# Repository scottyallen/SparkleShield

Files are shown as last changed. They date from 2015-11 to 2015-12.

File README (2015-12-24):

The Sparkle Shield is an add-on shield for Arduino that has 70 individually
programmable full color LEDs arranged in a 7x10 matrix. It comes as an
unassembled kit that you can solder yourself with a few basic tools.  The
Sparkle Shield comes with a bunch of cool animations, but it's also easy to
program your own using the free Arduino development kit (compatible with
PC/Mac/Linux) and the Sparkle Shield Arduino library.

For more information and assembly and programming instructions, go to
http://sparkleshield.com.

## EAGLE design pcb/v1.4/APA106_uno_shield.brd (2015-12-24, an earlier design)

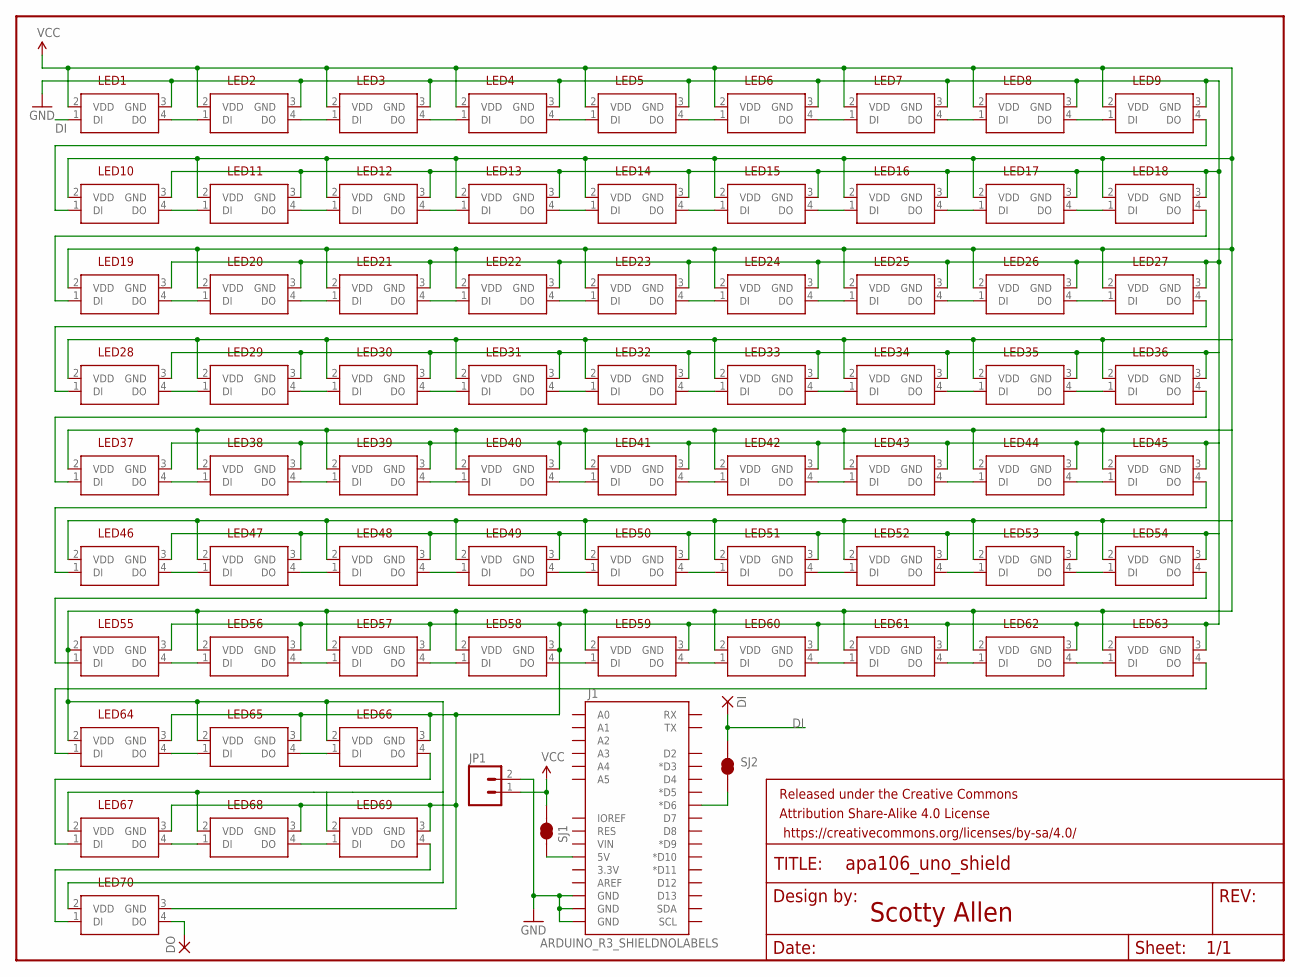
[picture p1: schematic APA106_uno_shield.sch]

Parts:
DI: 1,6/0,9
DO: 1,6/0,9
FRAME1: FRAME-LETTER; CREATIVE_COMMONS
J1: ARDUINO_R3_SHIELDNOLABELS; UNO_R3_SHIELD_NOLABELS
JP1: M02PTH; 1X02
LED1, LED2, LED3, LED4, LED5, LED6, LED7, LED8, LED9, LED10, LED11, LED12, LED13, LED14, LED15, LED16, LED17, LED18, LED19, LED20, LED21, LED22, LED23, LED24, LED25, LED26, LED27, LED28, LED29, LED30, LED31, LED32, LED33, LED34, LED35, LED36, LED37, LED38, LED39, LED40, LED41, LED42, LED43, LED44, LED45, LED46, LED47, LED48, LED49, LED50, LED51, LED52, LED53, LED54, LED55, LED56, LED57, LED58, LED59, LED60, LED61, LED62, LED63, LED64, LED65, LED66, LED67, LED68, LED69, LED70: LED-APA106HOLE-OFFSET-SPREAD; LED-5MM-4PIN-HOLE-OFFSET-SPREAD
SJ1, SJ2: JUMPER-PAD-2-NC_BY_TRACENO_SILK; PAD-JUMPER-2-NC_BY_TRACE_NO_SILK

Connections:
DI: DI.1, LED1.1 (DI), SJ2.2
GND: J1.GND@0 (GND), J1.GND@1 (GND), J1.GND@2 (GND), JP1.2, LED1.3 (GND), LED2.3 (GND), LED3.3 (GND), LED4.3 (GND), LED5.3 (GND), LED6.3 (GND), LED7.3 (GND), LED8.3 (GND), LED9.3 (GND), LED10.3 (GND), LED11.3 (GND), LED12.3 (GND), LED13.3 (GND), LED14.3 (GND), LED15.3 (GND), LED16.3 (GND), LED17.3 (GND), LED18.3 (GND), LED19.3 (GND), LED20.3 (GND), LED21.3 (GND), LED22.3 (GND), LED23.3 (GND), LED24.3 (GND), LED25.3 (GND), LED26.3 (GND), LED27.3 (GND), LED28.3 (GND), LED29.3 (GND), LED30.3 (GND), LED31.3 (GND), LED32.3 (GND), LED33.3 (GND), LED34.3 (GND), LED35.3 (GND), LED36.3 (GND), LED37.3 (GND), LED38.3 (GND), LED39.3 (GND), LED40.3 (GND), LED41.3 (GND), LED42.3 (GND), LED43.3 (GND), LED44.3 (GND), LED45.3 (GND), LED46.3 (GND), LED47.3 (GND), LED48.3 (GND), LED49.3 (GND), LED50.3 (GND), LED51.3 (GND), LED52.3 (GND), LED53.3 (GND), LED54.3 (GND), LED55.3 (GND), LED56.3 (GND), LED57.3 (GND), LED58.3 (GND), LED59.3 (GND), LED60.3 (GND), LED61.3 (GND), LED62.3 (GND), LED63.3 (GND), LED64.3 (GND), LED65.3 (GND), LED66.3 (GND), LED67.3 (GND), LED68.3 (GND), LED69.3 (GND), LED70.3 (GND)
unnamed: LED1.4 (DO), LED2.1 (DI)
unnamed: LED2.4 (DO), LED3.1 (DI)
unnamed: LED3.4 (DO), LED4.1 (DI)
unnamed: LED4.4 (DO), LED5.1 (DI)
unnamed: LED6.4 (DO), LED7.1 (DI)
unnamed: LED7.4 (DO), LED8.1 (DI)
unnamed: LED37.4 (DO), LED38.1 (DI)
unnamed: LED5.4 (DO), LED6.1 (DI)
unnamed: LED8.4 (DO), LED9.1 (DI)
unnamed: LED10.4 (DO), LED11.1 (DI)
unnamed: LED19.4 (DO), LED20.1 (DI)
unnamed: LED20.4 (DO), LED21.1 (DI)
unnamed: LED11.4 (DO), LED12.1 (DI)
unnamed: LED12.4 (DO), LED13.1 (DI)
unnamed: LED21.4 (DO), LED22.1 (DI)
unnamed: LED22.4 (DO), LED23.1 (DI)
unnamed: LED18.4 (DO), LED19.1 (DI)
unnamed: LED23.4 (DO), LED24.1 (DI)
unnamed: LED13.4 (DO), LED14.1 (DI)
unnamed: LED9.4 (DO), LED10.1 (DI)
unnamed: LED14.4 (DO), LED15.1 (DI)
unnamed: LED15.4 (DO), LED16.1 (DI)
unnamed: LED16.4 (DO), LED17.1 (DI)
unnamed: LED17.4 (DO), LED18.1 (DI)
unnamed: LED24.4 (DO), LED25.1 (DI)
unnamed: LED25.4 (DO), LED26.1 (DI)
unnamed: LED26.4 (DO), LED27.1 (DI)
unnamed: LED28.4 (DO), LED29.1 (DI)
unnamed: LED29.4 (DO), LED30.1 (DI)
unnamed: LED30.4 (DO), LED31.1 (DI)
unnamed: LED31.4 (DO), LED32.1 (DI)
unnamed: LED27.4 (DO), LED28.1 (DI)
unnamed: LED32.4 (DO), LED33.1 (DI)
unnamed: LED33.4 (DO), LED34.1 (DI)
unnamed: LED34.4 (DO), LED35.1 (DI)
unnamed: LED35.4 (DO), LED36.1 (DI)
unnamed: LED38.4 (DO), LED39.1 (DI)
unnamed: LED39.4 (DO), LED40.1 (DI)
unnamed: LED40.4 (DO), LED41.1 (DI)
unnamed: LED36.4 (DO), LED37.1 (DI)
unnamed: LED41.4 (DO), LED42.1 (DI)
unnamed: LED42.4 (DO), LED43.1 (DI)
unnamed: LED43.4 (DO), LED44.1 (DI)
unnamed: LED44.4 (DO), LED45.1 (DI)
unnamed: LED46.4 (DO), LED47.1 (DI)
unnamed: LED47.4 (DO), LED48.1 (DI)
unnamed: LED48.4 (DO), LED49.1 (DI)
unnamed: LED49.4 (DO), LED50.1 (DI)
unnamed: LED45.4 (DO), LED46.1 (DI)
unnamed: LED50.4 (DO), LED51.1 (DI)
unnamed: LED51.4 (DO), LED52.1 (DI)
unnamed: LED52.4 (DO), LED53.1 (DI)
unnamed: LED53.4 (DO), LED54.1 (DI)
unnamed: LED55.4 (DO), LED56.1 (DI)
unnamed: LED56.4 (DO), LED57.1 (DI)
unnamed: LED57.4 (DO), LED58.1 (DI)
unnamed: LED58.4 (DO), LED59.1 (DI)
unnamed: LED54.4 (DO), LED55.1 (DI)
unnamed: LED59.4 (DO), LED60.1 (DI)
unnamed: LED60.4 (DO), LED61.1 (DI)
unnamed: LED61.4 (DO), LED62.1 (DI)
unnamed: LED62.4 (DO), LED63.1 (DI)
unnamed: LED64.4 (DO), LED65.1 (DI)
unnamed: LED65.4 (DO), LED66.1 (DI)
unnamed: LED67.4 (DO), LED68.1 (DI)
unnamed: LED63.4 (DO), LED64.1 (DI)
unnamed: LED68.4 (DO), LED69.1 (DI)
unnamed: LED66.4 (DO), LED67.1 (DI)
unnamed: LED69.4 (DO), LED70.1 (DI)
unnamed: J1.5V, SJ1.1
unnamed: DO.1, LED70.4 (DO)
unnamed: J1.D6 (*D6), SJ2.1
VCC: JP1.1, LED1.2 (VDD), LED2.2 (VDD), LED3.2 (VDD), LED4.2 (VDD), LED5.2 (VDD), LED6.2 (VDD), LED7.2 (VDD), LED8.2 (VDD), LED9.2 (VDD), LED10.2 (VDD), LED11.2 (VDD), LED12.2 (VDD), LED13.2 (VDD), LED14.2 (VDD), LED15.2 (VDD), LED16.2 (VDD), LED17.2 (VDD), LED18.2 (VDD), LED19.2 (VDD), LED20.2 (VDD), LED21.2 (VDD), LED22.2 (VDD), LED23.2 (VDD), LED24.2 (VDD), LED25.2 (VDD), LED26.2 (VDD), LED27.2 (VDD), LED28.2 (VDD), LED29.2 (VDD), LED30.2 (VDD), LED31.2 (VDD), LED32.2 (VDD), LED33.2 (VDD), LED34.2 (VDD), LED35.2 (VDD), LED36.2 (VDD), LED37.2 (VDD), LED38.2 (VDD), LED39.2 (VDD), LED40.2 (VDD), LED41.2 (VDD), LED42.2 (VDD), LED43.2 (VDD), LED44.2 (VDD), LED45.2 (VDD), LED46.2 (VDD), LED47.2 (VDD), LED48.2 (VDD), LED49.2 (VDD), LED50.2 (VDD), LED51.2 (VDD), LED52.2 (VDD), LED53.2 (VDD), LED54.2 (VDD), LED55.2 (VDD), LED56.2 (VDD), LED57.2 (VDD), LED58.2 (VDD), LED59.2 (VDD), LED60.2 (VDD), LED61.2 (VDD), LED62.2 (VDD), LED63.2 (VDD), LED64.2 (VDD), LED65.2 (VDD), LED66.2 (VDD), LED67.2 (VDD), LED68.2 (VDD), LED69.2 (VDD), LED70.2 (VDD), SJ1.2

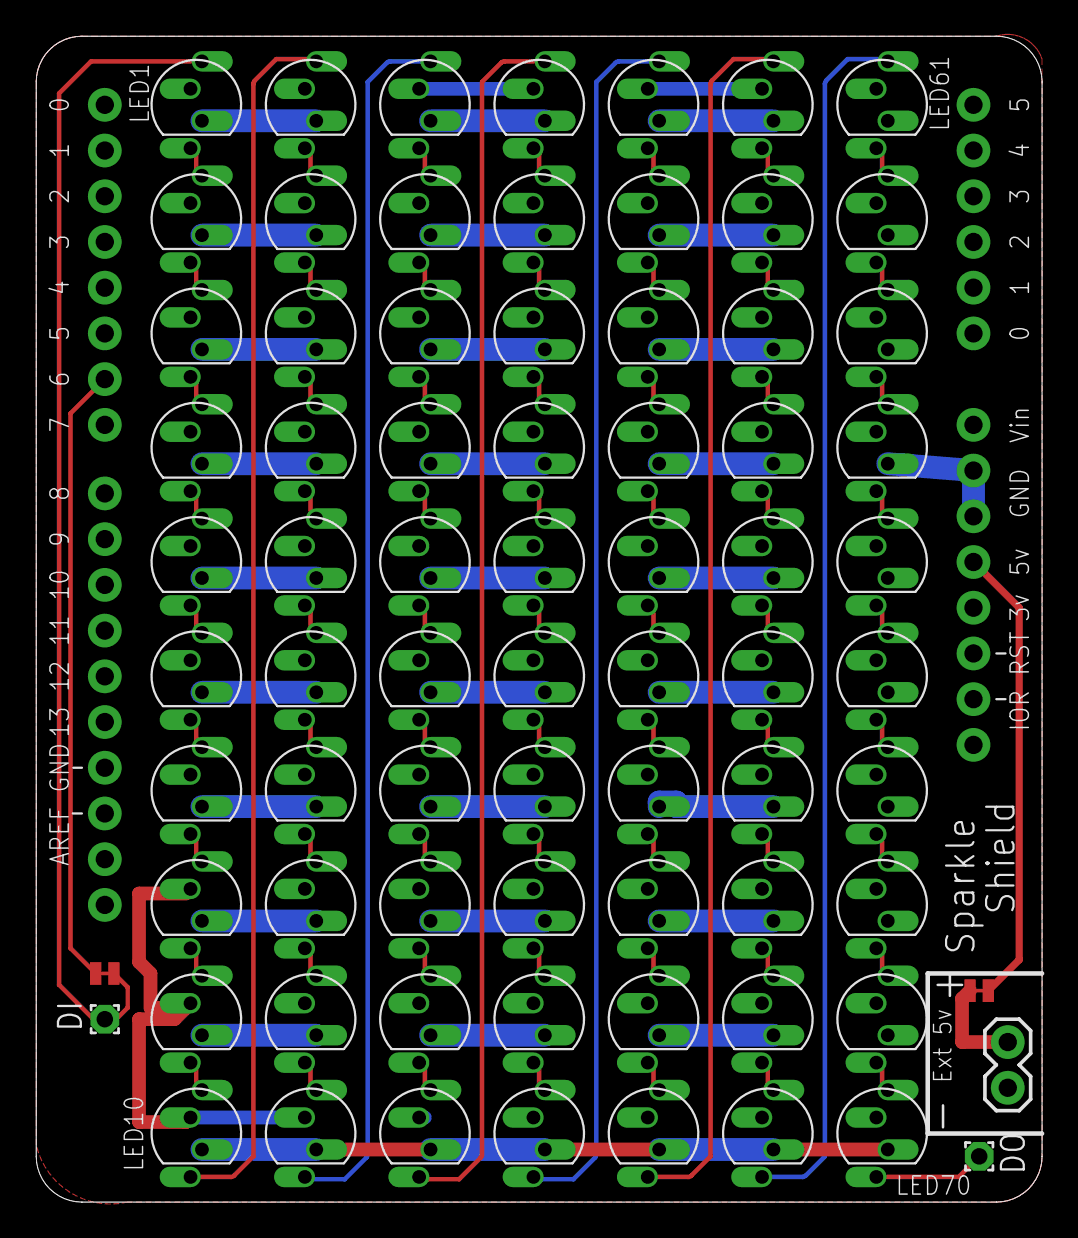
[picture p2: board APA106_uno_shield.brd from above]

Board: 2 copper layers, 55.9 x 64.8 mm, 77 parts (0 on the bottom side), 75 nets.

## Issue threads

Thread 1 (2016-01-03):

Matrix example fails to compile with "Math.h: No such file or directory"

LenzGr, 2016-01-03:
I purchased the SparkleShield at 32C3 in Hamburg and the assembly worked out of the box, thanks to the great instructions.

I installed the SparkleShield library as described on http://sparkleshield.com/pages/instructions and started toying around with the examples included.

My controller is a [Seeduino Mega](http://www.seeedstudio.com/wiki/index.php?title=Seeeduino_Mega) based on the ATmega 1280 processor.

My development environment: Arduino: 1.6.7 (Linux), Board: "Arduino/Genuino Mega or Mega 2560, ATmega1280"

However, compiling the "Matrix" Demo initially failed with the following error:
```
/home/lenz/Arduino/libraries/SparkleShield/examples/Matrix/Matrix.ino:3:18: fatal error: Math.h: No such file or directory
 #include <Math.h>
                  ^
compilation terminated.
exit status 1
Error compiling.
```

Simply removing or commenting out the ```#include <Math.h>``` directive fixes the compile error and the demo works as expected.

gedsic, 2016-01-03:
You have to include <math.h>, in lower case. I submitted a pull request.

LenzGr, 2016-01-03:
@gedsic : I did not have to include ```math.h``` at all to get it compile and run. Simply commenting out the include directive fixed the build error and the resulting binary works without problems.

gedsic, 2016-01-04:
@LenzGr You're right, math.h is included by default.

scottyallen, 2016-01-21:
I merged the pull request, so closing this out.  I'll leave math.h in for clarity sake.

Closed 2016-01-21.

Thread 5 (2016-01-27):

Header pins are too short

franciscop, 2016-01-27:
The male-male pins are too short and the soldered LEDs touch the USB connector and cannot be completely fitted in:

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

Even though I tried shortening them the maximum possible. Luckily joining both of the headers can solve this problem:

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

For future versions I recommend adding longer pin headers

Closed 2018-10-17.

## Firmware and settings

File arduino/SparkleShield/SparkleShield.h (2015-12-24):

/*
  SparkleShield.h - Library for controlling the Sparkle Shield LED display.
  Created by Scotty Allen, December 18, 2015.
  Released under a GPL v2 license.
*/

#ifndef SparkleShield_h
#define SparkleShield_h

#include "Arduino.h"
#include <FastLED.h>

#define COLOR_ORDER RGB
#define CHIPSET     WS2811
#define DEFAULT_LED_PIN  6
#define DEFAULT_BRIGHTNESS  32
const uint8_t kMatrixWidth = 10;
const uint8_t kMatrixHeight = 7;
#define NUM_LEDS (kMatrixWidth * kMatrixHeight)

class SparkleShield {
  public:
    SparkleShield();
    void show();
    uint16_t XY( uint8_t x, uint8_t y);
    uint16_t XYsafe( uint8_t x, uint8_t y);
    void setBrightness(uint8_t brightness);
    void set(uint8_t x, uint8_t y, CHSV color);
    void set(uint8_t x, uint8_t y, CRGB color);
    void scroll_text(char *text, CHSV color);
    void draw_text(int x, int y, char *text, CHSV color);
    void draw_sprite(int xOffset, int yOffset, unsigned char* sprite, int length, CHSV color);
    void clear();
    void clear(CHSV color);

    static CRGB leds_plus_safety_pixel[];
    static CRGB* leds;
};

#endif

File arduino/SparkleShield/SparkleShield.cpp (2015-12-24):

/*
  SparkleShield.cpp - Library for controlling the Sparkle Shield LED display.
  Created by Scotty Allen, December 18, 2015.
  Released under a GPL v2 license.
*/

#include "Arduino.h"
#include "SparkleShield.h"
#include <FastLED.h>

// TODO(scotty): Add ability to change pin and support chaining

CRGB SparkleShield::leds_plus_safety_pixel[ NUM_LEDS + 1];
CRGB* SparkleShield::leds( leds_plus_safety_pixel + 1);

SparkleShield::SparkleShield() {
  FastLED.addLeds<CHIPSET, DEFAULT_LED_PIN, COLOR_ORDER>(SparkleShield::leds, NUM_LEDS).setCorrection(TypicalSMD5050);
  FastLED.setBrightness(DEFAULT_BRIGHTNESS);
}

void SparkleShield::show() {
  FastLED.show();
}

void SparkleShield::setBrightness(uint8_t brightness) {
  FastLED.setBrightness(brightness);
}

// Helper functions for an two-dimensional XY matrix of pixels.
//
//     XY(x,y) takes x and y coordinates and returns an LED index number,
//             for use like this:  leds[ XY(x,y) ] == CRGB::Red;
//             No error checking is performed on the ranges of x and y.
//
//     XYsafe(x,y) takes x and y coordinates and returns an LED index number,
//             for use like this:  leds[ XY(x,y) ] == CRGB::Red;
//             Error checking IS performed on the ranges of x and y, and an
//             index of "-1" is returned.  Special instructions below
//             explain how to use this without having to do your own error
//             checking every time you use this function.
//             This is a slightly more advanced technique, and
//             it REQUIRES SPECIAL ADDITIONAL setup, described below.


// This function will return the right 'led index number' for
// a given set of X and Y coordinates on your matrix.
// IT DOES NOT CHECK THE COORDINATE BOUNDARIES.
// That's up to you.  Don't pass it bogus values.
//
// Use the "XY" function like this:
//
//    for( uint8_t x = 0; x < kMatrixWidth; x++) {
//      for( uint8_t y = 0; y < kMatrixHeight; y++) {
//
//        // Here's the x, y to 'led index' in action:
//        leds[ XY( x, y) ] = CHSV( random8(), 255, 255);
//
//      }
//    }
//
//
uint16_t SparkleShield::XY( uint8_t x, uint8_t y) {
  return (y * kMatrixWidth) + x;
}

// Here's a helpful technique that can be tricky to set up, but
// then helps you avoid the needs for sprinkling array-bound-checking
// throughout your code.
//
// It requires a careful attention to get it set up correctly, but
// can potentially make your code smaller and faster.
//
// Suppose you have an 8 x 5 matrix of 40 LEDs.  Normally, you'd
// delcare your leds array like this:
//    CRGB leds[40];
// But instead of that, declare an LED buffer with one extra pixel in
// it, "leds_plus_safety_pixel".  Then declare "leds" as a pointer to
// that array, but starting with the 2nd element (id=1) of that array:
//    CRGB leds_with_safety_pixel[41];
//    const CRGB* leds( leds_plus_safety_pixel + 1);
// Then you use the "leds" array as you normally would.
// Now "leds[0..N]" are aliases for "leds_plus_safety_pixel[1..(N+1)]",
// AND leds[-1] is now a legitimate and safe alias for leds_plus_safety_pixel[0].
// leds_plus_safety_pixel[0] aka leds[-1] is now your "safety pixel".
//
// Now instead of using the XY function above, use the one below, "XYsafe".
//
// If the X and Y values are 'in bounds', this function will return an index
// into the visible led array, same as "XY" does.
// HOWEVER -- and this is the trick -- if the X or Y values
// are out of bounds, this function will return an index of -1.
// And since leds[-1] is actually just an alias for leds_plus_safety_pixel[0],
// it's a totally safe and legal place to access.  And since the 'safety pixel'
// falls 'outside' the visible part of the LED array, anything you write
// there is hidden from view automatically.
// Thus, this line of code is totally safe, regardless of the actual size of
// your matrix:
//    leds[ XYsafe( random8(), random8() ) ] = CHSV( random8(), 255, 255);
//
// The only catch here is that while this makes it safe to read from and
// write to 'any pixel', there's really only ONE 'safety pixel'.  No matter
// what out-of-bounds coordinates you write to, you'll really be writing to
// that one safety pixel.  And if you try to READ from the safety pixel,
// you'll read whatever was written there last, reglardless of what coordinates
// were supplied.

uint16_t SparkleShield::XYsafe( uint8_t x, uint8_t y) {
  if ( x >= kMatrixWidth) return -1;
  if ( y >= kMatrixHeight) return -1;
  return XY(x, y);
}

void SparkleShield::set(uint8_t x, uint8_t y, CRGB color) {
  SparkleShield::leds[SparkleShield::XYsafe(x, y)] = color;
}

void SparkleShield::set(uint8_t x, uint8_t y, CHSV color) {
  SparkleShield::leds[SparkleShield::XYsafe(x, y)] = color;
}

unsigned char* Char(unsigned char* font, char c) {
  return &font[(c - 32) * 5];
}

static unsigned char Font5x7[] = {
  0x00, 0x00, 0x00, 0x00, 0x00,// (space)
  0x00, 0x00, 0x5F, 0x00, 0x00,// !
  0x00, 0x07, 0x00, 0x07, 0x00,// "
  0x14, 0x7F, 0x14, 0x7F, 0x14,// #
  0x24, 0x2A, 0x7F, 0x2A, 0x12,// $
  0x23, 0x13, 0x08, 0x64, 0x62,// %
  0x36, 0x49, 0x55, 0x22, 0x50,// &
  0x00, 0x05, 0x03, 0x00, 0x00,// '
  0x00, 0x1C, 0x22, 0x41, 0x00,// (
  0x00, 0x41, 0x22, 0x1C, 0x00,// )
  0x08, 0x2A, 0x1C, 0x2A, 0x08,// *
  0x08, 0x08, 0x3E, 0x08, 0x08,// +
  0x00, 0x50, 0x30, 0x00, 0x00,// ,
  0x08, 0x08, 0x08, 0x08, 0x08,// -
  0x00, 0x60, 0x60, 0x00, 0x00,// .
  0x20, 0x10, 0x08, 0x04, 0x02,// /
  0x3E, 0x51, 0x49, 0x45, 0x3E,// 0
  0x00, 0x42, 0x7F, 0x40, 0x00,// 1
  0x42, 0x61, 0x51, 0x49, 0x46,// 2
  0x21, 0x41, 0x45, 0x4B, 0x31,// 3
  0x18, 0x14, 0x12, 0x7F, 0x10,// 4
  0x27, 0x45, 0x45, 0x45, 0x39,// 5
  0x3C, 0x4A, 0x49, 0x49, 0x30,// 6
  0x01, 0x71, 0x09, 0x05, 0x03,// 7
  0x36, 0x49, 0x49, 0x49, 0x36,// 8
  0x06, 0x49, 0x49, 0x29, 0x1E,// 9
  0x00, 0x36, 0x36, 0x00, 0x00,// :
  0x00, 0x56, 0x36, 0x00, 0x00,// ;
  0x00, 0x08, 0x14, 0x22, 0x41,// <
  0x14, 0x14, 0x14, 0x14, 0x14,// =
  0x41, 0x22, 0x14, 0x08, 0x00,// >
  0x02, 0x01, 0x51, 0x09, 0x06,// ?
  0x32, 0x49, 0x79, 0x41, 0x3E,// @
  0x7E, 0x11, 0x11, 0x11, 0x7E,// A
  0x7F, 0x49, 0x49, 0x49, 0x36,// B
  0x3E, 0x41, 0x41, 0x41, 0x22,// C
  0x7F, 0x41, 0x41, 0x22, 0x1C,// D
  0x7F, 0x49, 0x49, 0x49, 0x41,// E
  0x7F, 0x09, 0x09, 0x01, 0x01,// F
  0x3E, 0x41, 0x41, 0x51, 0x32,// G
  0x7F, 0x08, 0x08, 0x08, 0x7F,// H
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
};

void SparkleShield::draw_text(int x, int y, char *text, CHSV color) {
  for (int i = 0; i < strlen(text); i++) {
    SparkleShield::draw_sprite(x + i * 6, y, Char(Font5x7, text[i]), 5, color);
  }
}

void SparkleShield::draw_sprite(int xOffset, int yOffset, unsigned char* sprite, int length, CHSV color) {
  //  leds[ XYsafe(x, y) ] = CHSV(0, 0, 255);
  for(byte y = 0; y < 7; y++) {
    for(byte x = 0; x < 5; x++) {
      bool on = (sprite[x] >> (6 - y) & 1) * 255;
      if (on) {
        SparkleShield::set(x + xOffset, y + yOffset, color);
      }
    }
  }
}
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

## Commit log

2015-11-08 v2 of boards
    [APA106_layout_test.brd, APA106_layout_test.sch, APA106_uno_shield.brd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]
2015-11-16 Move v2 designs to v2 folder.
    [APA106_uno_shield.brd, APA106_uno_shield.sch]
2015-11-16 final v3 board designs.
    [APA106_uno_shield.brd, APA106_uno_shield.sch]
2015-12-24 v1.4 of board design
    - Changed name
    - Add url
    - make board narrower to allow better tiling of multiple boards.
    [APA106_uno_shield.brd, APA106_uno_shield.sch]
2015-12-24 Setup an arduino library
2015-12-24 A very simple animation to light each led in sequence.
2015-12-24 Clean up pcb design files.
    [APA106_layout_test.brd, APA106_layout_test.sch, APA106_uno_shield.brd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]
2015-12-24 Bundle arduino code as a zip file
2015-12-28 Fix text scrolling example
    [TextScroll.ino]
2016-01-03 Fixed typo that prevented compiling matrix example on Linux
    [Matrix.ino]
2016-09-22 Fix problem compiling in Russian on Windows.
    For some reason, when the arduino IDE is set to Russian on Windows, it
    requires all functions to be declared before they are used.
    So this reorders functions in the examples to always define them before they are used.
    [Matrix.ino, Rainbow.ino]
2016-09-22 Demo animation that includes all the various examples.
    Restart the arduino (or hit the reset button) to go to the next animation.
2016-09-22 Fix Demo on Russian Windows.
    [Demo.ino]

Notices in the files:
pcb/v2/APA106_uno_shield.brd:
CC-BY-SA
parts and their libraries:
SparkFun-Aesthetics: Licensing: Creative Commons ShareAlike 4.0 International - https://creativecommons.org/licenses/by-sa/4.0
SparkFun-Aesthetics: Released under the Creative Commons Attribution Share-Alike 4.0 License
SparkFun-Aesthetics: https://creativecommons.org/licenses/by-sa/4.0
